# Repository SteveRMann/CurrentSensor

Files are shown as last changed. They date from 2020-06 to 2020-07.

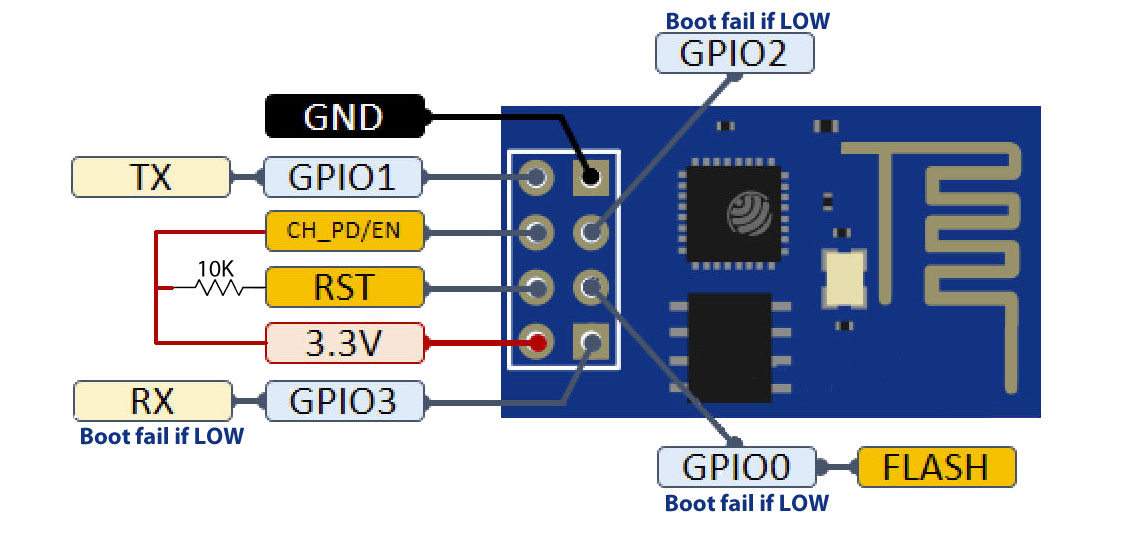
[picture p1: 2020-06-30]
ESP8266-01 gpio pins.jpg

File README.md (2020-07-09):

## **Current Sensor**

### **What is the Current Sensor for?**

The current sensor is designed to provide feedback via mqtt status messages for devices that have
no such ability.
For example, if the television is controlled by an mqtt relay, there is no status message telling the 
controller if the TV is on or off in the first place.

### **How to use it**
There is a sense wire on the PCB. This sense wire is to be placed around or adjacent to the "live" side
of the power cable to the device.  When properly placed, the LED on the board will turn on or off as the
power to the device is turned on or off.

#### **`Acknowledgements`**
This project was inspired by a You Tube video by Ralph Bacon:
'No contact mains detector for Arduino & Pi'.
https://www.youtube.com/watch?v=cDuObAR42Nw

I simply put his circuit on a PCB, added an ESP8266-01 and the Arduino code.

##**The remainder is for appearance experiments only**

CA3046
TPQ3904

```Arduino
#include <EEPROM.h>

void setup(){

}

void loop(){

}

```

The library provides a global variable named `EEPROM`, you use this variable to access the library functions. The methods provided in the EEPROM class are listed below.

You can view all the examples [here](examples/).

### **Library functions**

#### **`EEPROM.read( address )`** [[_example_]](examples/eeprom_read/eeprom_read.ino)

This function allows you to read a single byte of data from the eeprom.
Its only parameter is an `int` which should be set to the address you wish to read.

The function returns an `unsigned char` containing the value read.

#### **`EEPROM.write( address, value )`** [[_example_]](examples/eeprom_write/eeprom_write.ino)

The `write()` method allows you to write a single byte of data to the EEPROM.
Two parameters are needed. The first is an `int` containing the address that is to be written, and the second is a the data to be written (`unsigned char`).

This function does not return any value.

#### **`EEPROM.update( address, value )`** [[_example_]](examples/eeprom_update/eeprom_update.ino)

This function is similar to `EEPROM.write()` however this method will only write data if the cell contents pointed to by `address` is different to `value`. This method can help prevent unnecessary wear on the EEPROM cells.

This function does not return any value.

#### **`EEPROM.get( address, object )`** [[_example_]](examples/eeprom_get/eeprom_get.ino)

This function will retrieve any object from the EEPROM.
Two parameters are needed to call this function. The first is an `int` containing the address that is to be written, and the second is the object you would like to read.

This function returns a reference to the `object` passed in. It does not need to be used and is only returned for conveience.

#### **`EEPROM.put( address, object )`** [[_example_]](examples/eeprom_put/eeprom_put.ino)

This function will write any object to the EEPROM.
Two parameters are needed to call this function. The first is an `int` containing the address that is to be written, and the second is the object you would like to write.

This function uses the _update_ method to write its data, and therefore only rewrites changed cells.

This function returns a reference to the `object` passed in. It does not need to be used and is only returned for conveience.

#### **Subscript operator: `EEPROM[address]`** [[_example_]](examples/eeprom_crc/eeprom_crc.ino)

This operator allows using the identifier `EEPROM` like an array.  
EEPROM cells can be read _and_ **_written_** directly using this method.

This operator returns a reference to the EEPROM cell.

```c++
unsigned char val;

//Read first EEPROM cell.
val = EEPROM[ 0 ];

//Write first EEPROM cell.
EEPROM[ 0 ] = val;

//Compare contents
if( val == EEPROM[ 0 ] ){
  //Do something...
}
```

#### **`EEPROM.length()`**

This function returns an `unsigned int` containing the number of cells in the EEPROM.

---

### **Advanced features**

This library uses a component based approach to provide its functionality. This means you can also use these components to design a customized approach. Two background classes are available for use: `EERef` & `EEPtr`.

#### **`EERef` class**

This object references an EEPROM cell.
Its purpose is to mimic a typical byte of RAM, however its storage is the EEPROM.
This class has an overhead of two bytes, similar to storing a pointer to an EEPROM cell.

```C++
EERef ref = EEPROM[ 10 ]; //Create a reference to 11th cell.

ref = 4; //write to EEPROM cell.

unsigned char val = ref; //Read referenced cell.
```

#### **`EEPtr` class**

This object is a bidirectional pointer to EEPROM cells represented by `EERef` objects.
Just like a normal pointer type, this type can be dereferenced and repositioned using 
increment/decrement operators.

```C++
EEPtr ptr = 10; //Create a pointer to 11th cell.

*ptr = 4; //dereference and write to EEPROM cell.

unsigned char val = *ptr; //dereference and read.

ptr++; //Move to next EEPROM cell.
```

#### **`EEPROM.begin()`**

This function returns an `EEPtr` pointing to the first cell in the EEPROM.  
This is useful for STL objects, custom iteration and C++11 style ranged for loops.

#### **`EEPROM.end()`**

This function returns an `EEPtr` pointing at the location after the last EEPROM cell.  
Used with `begin()` to provide custom iteration.

**Note:** The `EEPtr` returned is invalid as it is out of range. Infact the hardware causes wrapping of the address (overflow) and `EEPROM.end()` actually references the first EEPROM cell.

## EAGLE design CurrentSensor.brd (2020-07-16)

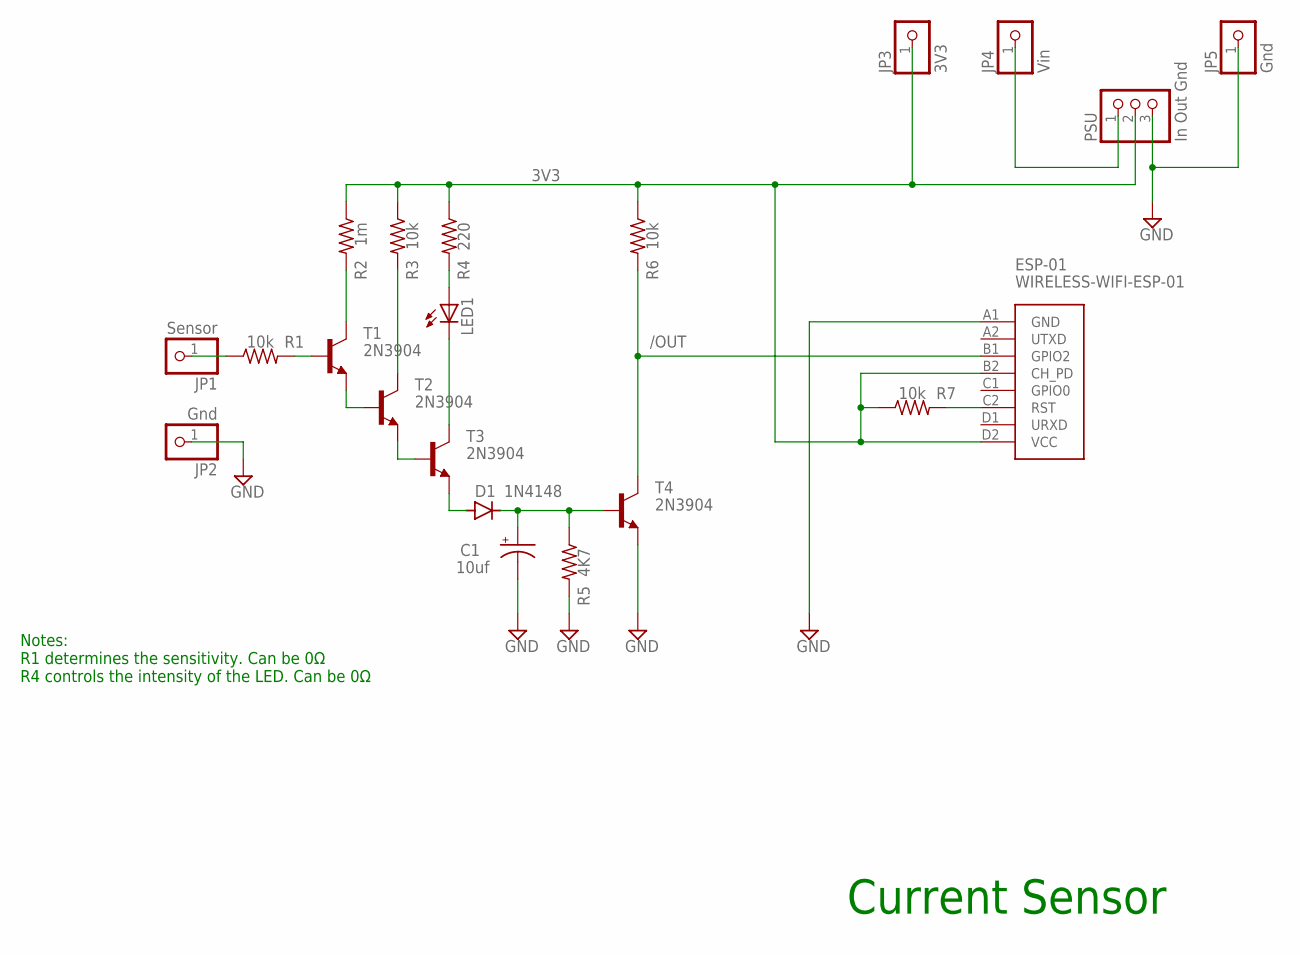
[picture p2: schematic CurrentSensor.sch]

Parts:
C1: 10uf; E15-5
D1: 1N4148; DO35-10
ESP-01: WIRELESS-WIFI-ESP-01
JP1: Sensor; 1X01
JP2: Gnd; 1X01
JP3: 3V3; 1X01-CLEANBIG
JP4: Vin; 1X01-CLEANBIG
JP5: Gnd; 1X01-CLEANBIG
LED1: LED5MM
PSU: In Out Gnd; 1X03-CLEANBIG
R1, R3, R6, R7: 10k; 0207/9
R2: 1m; 0207/9
R4: 220; 0207/9
R5: 4K7; 0207/9
T1, T2, T3, T4: 2N3904; TO92

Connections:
3V3: ESP-01.B2 (CH_PD), ESP-01.D2 (VCC), JP3.1, PSU.2, R2.1, R3.1, R4.1, R6.1, R7.1
/OUT: ESP-01.B1 (GPIO2), R6.2, T4.1 (C)
GND: C1.-, ESP-01.A1 (GND), JP2.1, JP5.1, PSU.3, R5.2, T4.3 (E)
unnamed: JP4.1, PSU.1
unnamed: JP1.1, R1.1
unnamed: T1.3 (E), T2.2 (B)
unnamed: T2.3 (E), T3.2 (B)
unnamed: D1.A, T3.3 (E)
unnamed: C1.+, D1.C, R5.1, T4.2 (B)
unnamed: LED1.K (C), T3.1 (C)
unnamed: LED1.A, R4.2
unnamed: R3.2, T2.1 (C)
unnamed: R2.2, T1.1 (C)
unnamed: R1.2, T1.2 (B)
unnamed: ESP-01.C2 (RST), R7.2

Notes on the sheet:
Current Sensor
Notes: R1 determines the sensitivity. Can be 0Ω R4 controls the intensity of the LED. Can be 0Ω

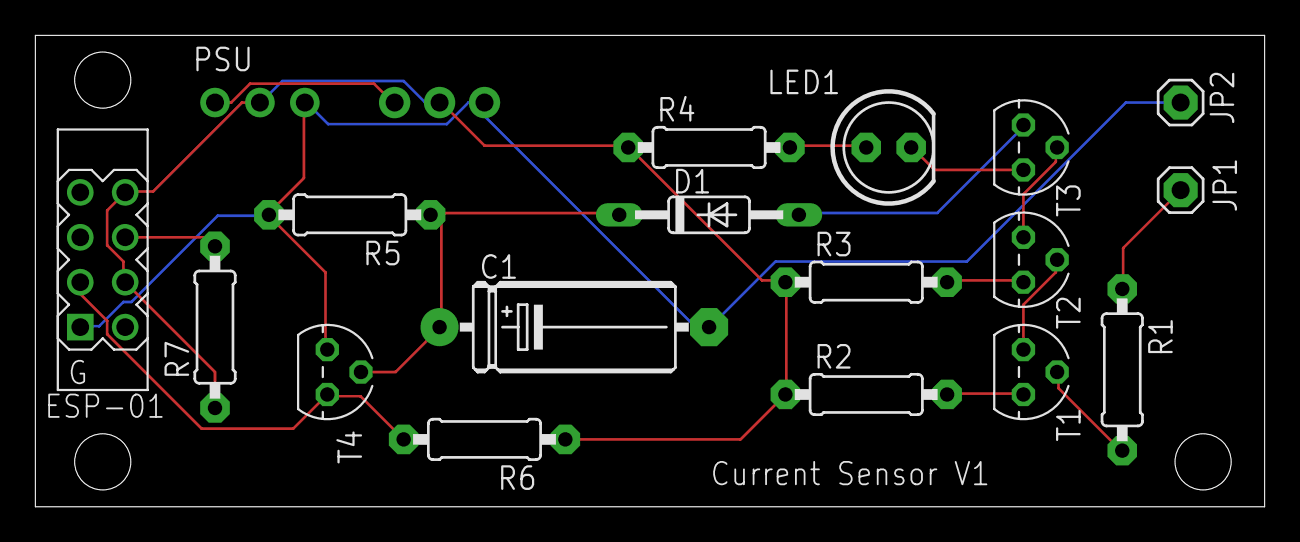
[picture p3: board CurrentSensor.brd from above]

Board: 2 copper layers, 69.5 x 26.7 mm, 21 parts (0 on the bottom side), 15 nets.

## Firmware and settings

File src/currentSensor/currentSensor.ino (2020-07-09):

#define sketchName "currentSensor.ino"
#define sketchVersion "Version 1.0 (7/10/2020)"
#define hostPrefix "iSense-"     // 6-chars MAX. Used by setup_wifi()

/*
  This project provides current sensing MQTT messages for devices that have no feedback
  to Home Assistant or Node-Red.  A television or washing-machine, for example
*/

#include <ArduinoOTA.h>
#include <ESP8266WiFi.h>        // Connect (and reconnect) an ESP8266 to the a WiFi network.
#include <PubSubClient.h>       // connect to a MQTT broker and publish/subscribe messages in topics.

#include "D:\River Documents\Arduino\libraries\Kaywinnet.h"  \\ WiFi credentials


char macBuffer[24];             // Holds the last three digits of the MAC, in hex.
char hostNamePrefix[] = hostPrefix;
char hostName[12];              // Holds hostNamePrefix + the last three bytes of the MAC address.
IPAddress myIP;                 // Holds the IP address
int rssi;


// ********** Globals **********
#define DEBUG false              //Set to true for debug output, false for no debug ouput
#define Serial if(DEBUG)Serial

#define NODENAME "currentSensor4"
const char *statusTopic = NODENAME "/status";               // Status is the most recent button number, 1-8, pressed.
const char *connectName =  NODENAME "sensor";               // Must be unique on the network
const char *mqttServer = mqtt_server;                       // Local broker defined in Kaywinnet.h
//const char *mqttServer = "broker.hivemq.com";
const int mqttPort = 1883;

// Declare an object of class WiFiClient, which allows to establish a connection to a specific IP and port
// Declare an object of class PubSubClient, which receives as input of the constructor the previously defined WiFiClient.
// The constructor MUST be unique on the network.
WiFiClient currentSensor1Client;
PubSubClient client(currentSensor1Client);

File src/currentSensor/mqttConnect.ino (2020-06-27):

// ================================== mqttConnect() =================================
// Connect or Reconnect to MQTT broker
// Make sure these two lines are at the beginning or end of the loop()
//  //Make sure we stay connected to the mqtt broker
//  if (!client.loop()) client.connect(connectName);


void mqttConnect() {
  // Loop until we're Connected
  while (!client.connected()) {
    Serial.print(F("Attempting MQTT connection..."));

    // Attempt to connect
    if (client.connect(connectName)) {
      Serial.println(F("connected"));

      //client.setCallback(callback);

      //Subscribe or resubscribe to a topic
      //client.subscribe(incomingTopic);
      //Serial.print(F("Subscribing to "));
      //Serial.println(incomingTopic);
      //Serial.println();
    } else {
      Serial.print(F("failed, rc="));
      Serial.print(String(client.state()));
      Serial.println(F(" try again in 5 seconds"));
      delay(5000);
    }
  }
}

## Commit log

2020-06-29 Added LED on GPIO2
    The function blinkLed() switches pin2 mode to output, flashes the LED then sets the pinmode back to input.
2020-06-29 Removed LED
2020-06-30 Added GPIO pinout drawing, cleaned up schematic
    [Dash4.brd, Dash4.sch]
2020-06-30 Annotated schematic
2020-06-30 Removed all references to LED
2020-07-09 Initial files
    [CurrentSensor.brd, CurrentSensor.sch]
2020-07-16 Add files via upload
    Added an on-board regulator.
    [CurrentSensor.brd, CurrentSensor.sch]
